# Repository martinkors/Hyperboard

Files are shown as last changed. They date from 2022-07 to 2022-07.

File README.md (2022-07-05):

# Hyperboard

A custom development board based on an STM32F479VIT6, used to test custom written drivers.

This board is only a prototype, there are many things that could be improved. It is not advised to follow the design of this board, but instead only use it as a very simplified reference board.

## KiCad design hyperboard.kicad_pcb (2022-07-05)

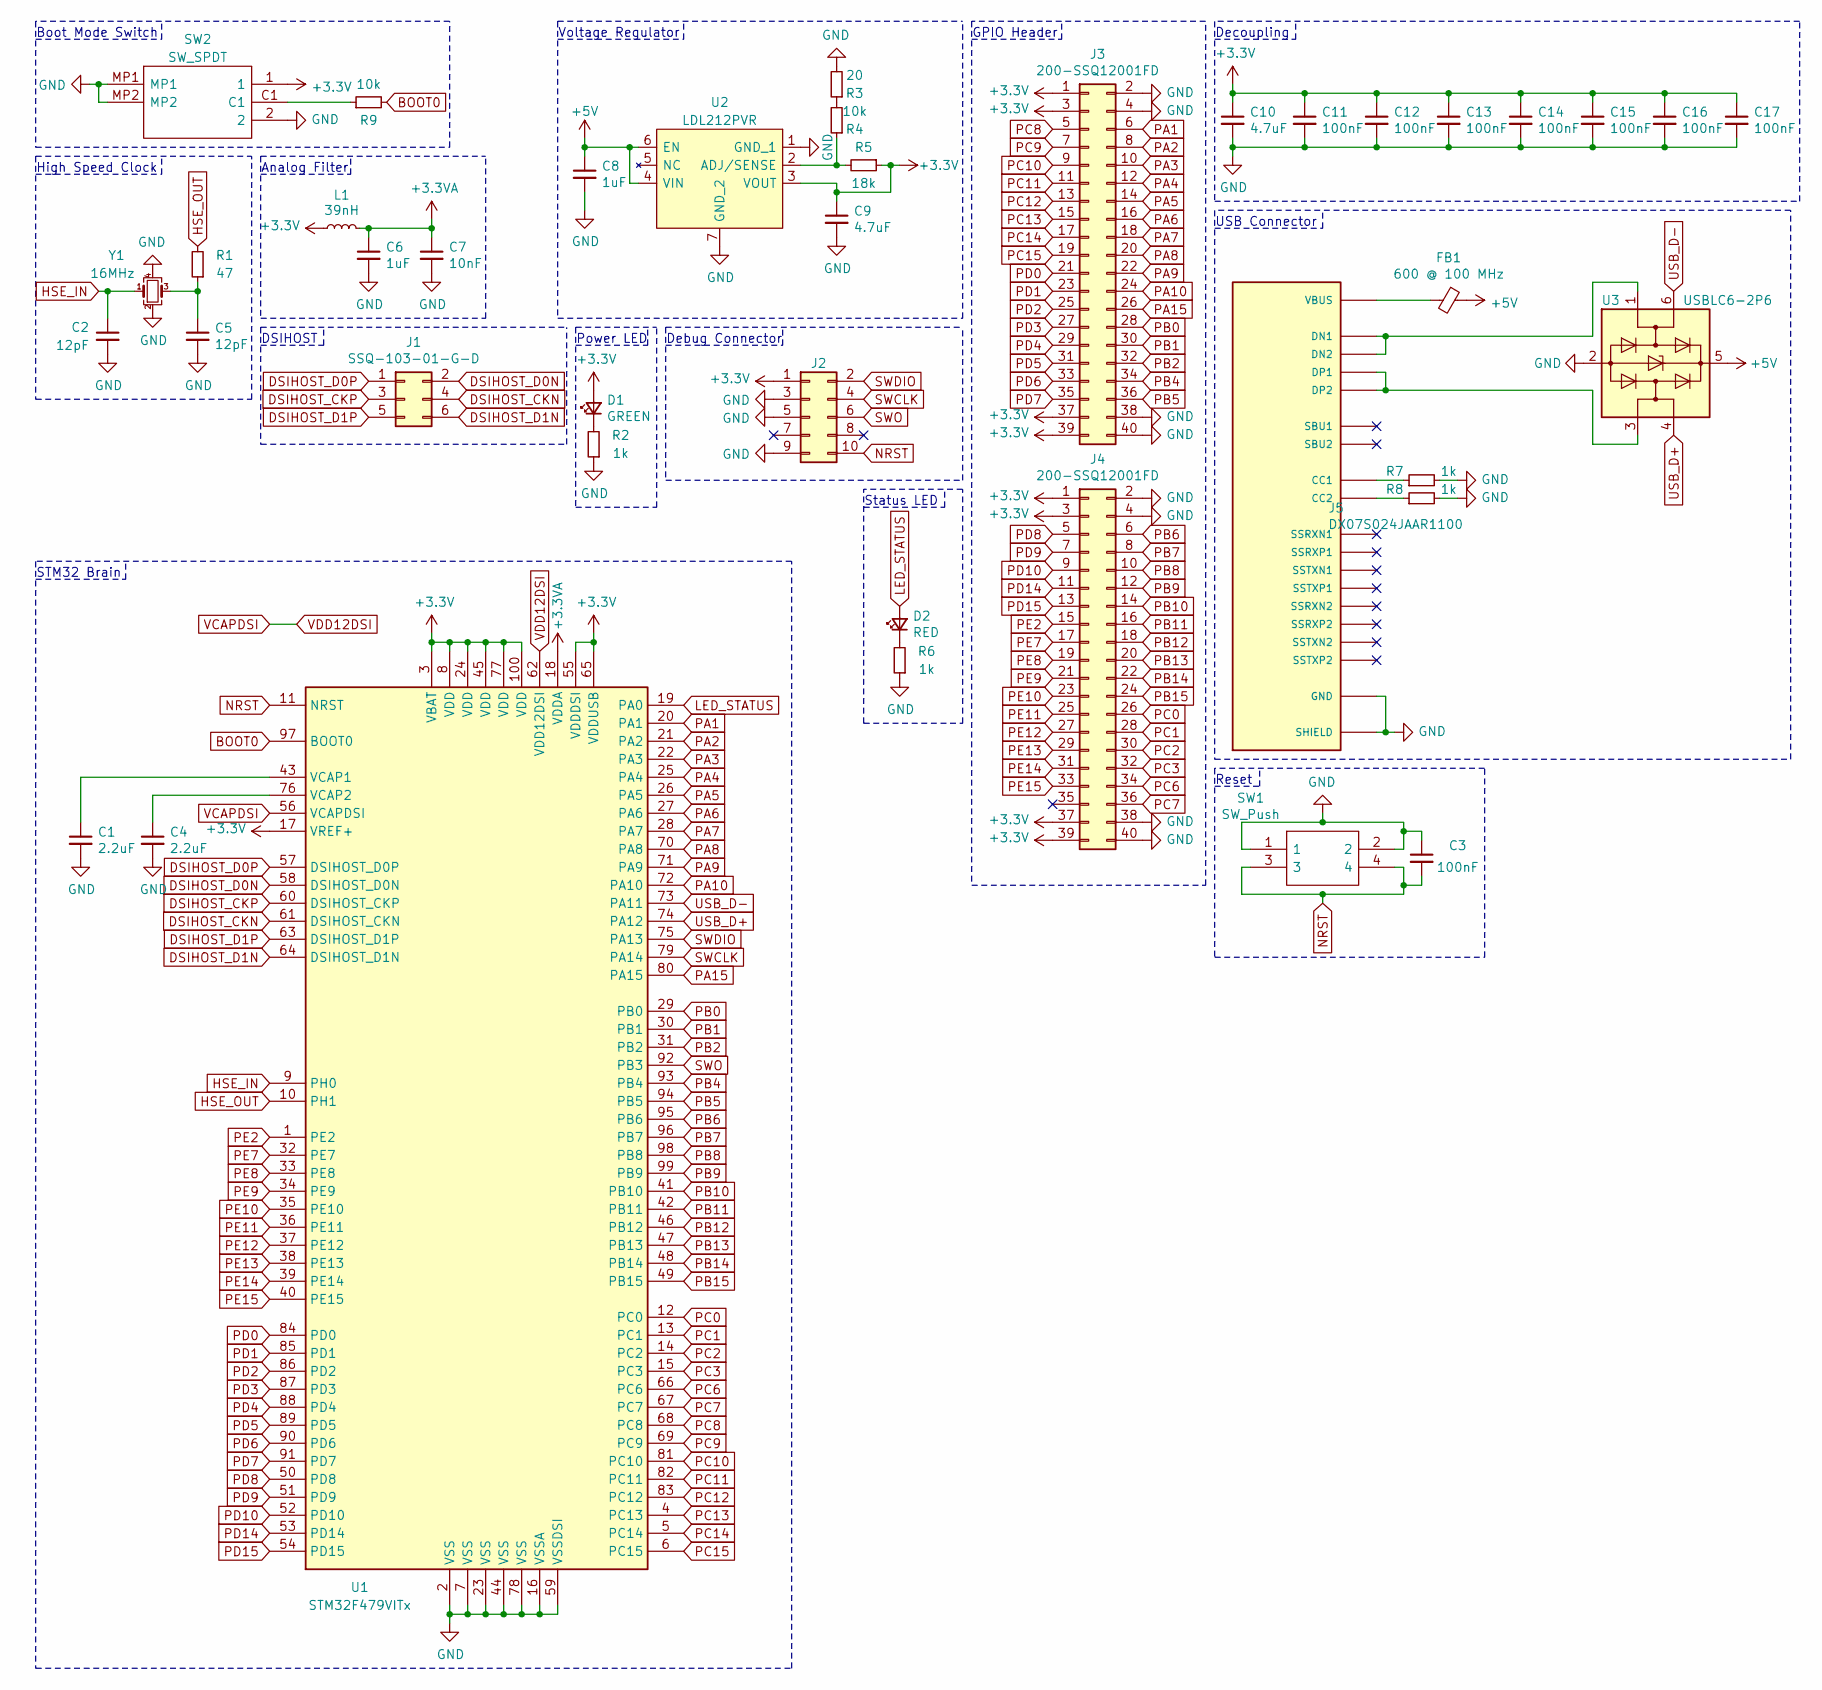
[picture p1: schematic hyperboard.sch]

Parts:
C1, C4: 2.2uF; C_0603_1608Metric; Mouser Part Number 187-CL10A225KA8NNNC; LCSC Part # C23630
C2, C5: 12pF; C_0603_1608Metric; Mouser Part Number 187-CL10C120JB81PNC; LCSC Part # C38523
C3, C11, C12, C13, C14, C15, C16, C17: 100nF; C_0402_1005Metric; Mouser Part Number 187-CL05B104KQ5NNNC; LCSC Part # C1525
C6: 1uF; C_0402_1005Metric; Mouser Part Number 187-CL05A105KQ5NNNC; LCSC Part # C52923
C7: 10nF; C_0402_1005Metric; Mouser Part Number 187-CL05B103JO5NNNC; LCSC Part # C15195
C8: 1uF; C_0402_1005Metric; Mouser Part Number 187-CL05A105KQ5NNNC; LCSC Part # C1525
C9: 4.7uF; C_0603_1608Metric; Mouser Part Number 187-CL10A475KQ8NNNC; LCSC Part # C1525
C10: 4.7uF; C_0603_1608Metric; Mouser Part Number 187-CL10A475KQ8NNNC; LCSC Part # C19666
D1: GREEN; LED_0805_2012Metric; Mouser Part Number 710-150080VS75000; LCSC Part # C188728
D2: RED; LED_0805_2012Metric; Mouser Part Number 710-150080RS75000; LCSC Part # C729289
FB1: 600 @ 100 MHz; L_0805_2012Metric; Mouser Part Number 710-742792040; LCSC Part # C1017
J1: SSQ-103-01-G-D; PinSocket_2x03_P2.54mm_Vertical; Mouser Part Number 200-SSQ10301GD
J2: FTSH-105-01-L-DV-K-TR; FTSH10501LDVKTR; Mouser Part Number 200-FTSH10501LDVKTR
J3, J4: 200-SSQ12001FD; SSQ-120-XX-YYY-D; Mouser Part Number 200-SSQ12001FD
J5: DX07S024JAAR1100; PARTREV 1.03; Mouser Part Number 656-DX07S024JAAR1100
L1: 39nH; L_0402_1005Metric; Mouser Part Number 710-7447840139; LCSC Part # C26443
R1: 47; R_0603_1608Metric; Mouser Part Number 667-ERJ-UP3J470V; LCSC Part # C23182
R2, R6, R7, R8: 1k; R_0603_1608Metric; Mouser Part Number 667-ERJ-UP3F1001V; LCSC Part # C21190
R3: 20; R_0603_1608Metric; Mouser Part Number 667-ERJ-UP3F20R0V; LCSC Part # C21190
R4: 10k; R_0603_1608Metric; Mouser Part Number 667-ERJ-UP3F1002V; LCSC Part # C22967
R5: 18k; R_0603_1608Metric; Mouser Part Number 667-ERJ-UP3F1802V; LCSC Part # C25804
R9: 10k; R_0603_1608Metric; Mouser Part Number 667-ERJ-UP3F1002V; LCSC Part # C25804
SW1: SW_Push; SKQGAKE010; Mouser Part Number 688-SKQGAKE010
SW2: SW_SPDT; JSX08001SAQNL; Mouser Part Number 688-SSAJ120100; LCSC Part # C319019
U1: STM32F479VITx; LQFP-100_14x14mm_P0.5mm; Mouser Part Number 511-STM32F479VIT6
U2: LDL212PVR; DFN-6-1EP_2x2mm_P0.65mm_EP1x1.6mm; Mouser Part Number 511-LDL212PVR; LCSC Part # C9056
U3: USBLC6-2P6; SOT-666; Mouser Part Number 511-USBLC6-2P6; LCSC Part # C7519
Y1: 16MHz; Crystal_SMD_3225-4Pin_3.2x2.5mm; Mouser Part Number 344-NX3225SA16MHZT1; LCSC Part # C13738

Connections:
+3.3VA: C6.1, C7.1, L1.2, U1.18 (VDDA)
+3V3: C9.1, C10.1, C11.1, C12.1, C13.1, C14.1, C15.1, C16.1, C17.1, D1.2 (A), J2.1, J3.1, J3.3, J3.37, J3.39, J4.1, J4.3, J4.37, J4.39, L1.1, R5.1, SW2.1, U1.3 (VBAT), U1.8 (VDD), U1.17 (VREF+), U1.24 (VDD), U1.45 (VDD), U1.55 (VDDDSI), U1.65 (VDDUSB), U1.77 (VDD), U1.100 (VDD), U2.3 (VOUT)
+5V: C8.1, FB1.1, U2.4 (VIN), U2.6 (EN), U3.5 (VBUS)
BOOT0: R9.2, U1.97 (BOOT0)
DSIHOST_CKN: J1.4, U1.61 (DSIHOST_CKN)
DSIHOST_CKP: J1.3, U1.60 (DSIHOST_CKP)
DSIHOST_D0N: J1.2, U1.58 (DSIHOST_D0N)
DSIHOST_D0P: J1.1, U1.57 (DSIHOST_D0P)
DSIHOST_D1N: J1.6, U1.64 (DSIHOST_D1N)
DSIHOST_D1P: J1.5, U1.63 (DSIHOST_D1P)
GND: C1.2, C2.2, C3.1, C4.2, C5.2, C6.2, C7.2, C8.2, C9.2, C10.2, C11.2, C12.2, C13.2, C14.2, C15.2, C16.2, C17.2, J2.3, J2.5, J2.9, J3.2, J3.4, J3.38, J3.40, J4.2, J4.4, J4.38, J4.40, J5.1 (SHIELD), J5.2 (SHIELD), J5.3 (SHIELD), J5.4 (SHIELD), J5.A1 (GND), J5.A12 (GND), J5.B1 (GND), J5.B12 (GND), R2.1, R3.2, R6.1, R7.2, R8.2, SW1.1, SW1.2, SW2.2, SW2.MP1, SW2.MP2, U1.2 (VSS), U1.7 (VSS), U1.16 (VSSA), U1.23 (VSS), U1.44 (VSS), U1.59 (VSSDSI), U1.78 (VSS), U2.1 (GND_1), U2.7 (GND_2), U3.2 (GND), Y1.2, Y1.4
HSE_IN: C2.1, U1.9 (PH0), Y1.1
HSE_OUT: R1.2, U1.10 (PH1)
LED_STATUS: D2.2 (A), U1.19 (PA0)
NRST: C3.2, J2.10, SW1.3, SW1.4, U1.11 (NRST)
unnamed: C1.1, U1.43 (VCAP1)
unnamed: C4.1, U1.76 (VCAP2)
unnamed: C5.1, R1.1, Y1.3
unnamed: D1.1 (K), R2.2
unnamed: D2.1 (K), R6.2
unnamed: FB1.2, J5.A4 (VBUS), J5.A9 (VBUS), J5.B4 (VBUS), J5.B9 (VBUS)
unnamed: J5.A5 (CC1), R7.1
unnamed: J5.A6 (DP1), J5.B6 (DP2), U3.3 (I/O2)
unnamed: J5.A7 (DN1), J5.B7 (DN2), U3.1 (I/O1)
unnamed: J5.B5 (CC2), R8.1
unnamed: R3.1, R4.2
unnamed: R4.1, R5.2, U2.2 (ADJ/SENSE)
unnamed: R9.1, SW2.C1
PA1: J3.6, U1.20 (PA1)
PA2: J3.8, U1.21 (PA2)
PA3: J3.10, U1.22 (PA3)
PA4: J3.12, U1.25 (PA4)
PA5: J3.14, U1.26 (PA5)
PA6: J3.16, U1.27 (PA6)
PA7: J3.18, U1.28 (PA7)
PA8: J3.20, U1.70 (PA8)
PA9: J3.22, U1.71 (PA9)
PA10: J3.24, U1.72 (PA10)
PA15: J3.26, U1.80 (PA15)
PB0: J3.28, U1.29 (PB0)
PB1: J3.30, U1.30 (PB1)
PB2: J3.32, U1.31 (PB2)
PB4: J3.34, U1.93 (PB4)
PB5: J3.36, U1.94 (PB5)
PB6: J4.6, U1.95 (PB6)
PB7: J4.8, U1.96 (PB7)
PB8: J4.10, U1.98 (PB8)
PB9: J4.12, U1.99 (PB9)
PB10: J4.14, U1.41 (PB10)
PB11: J4.16, U1.42 (PB11)
PB12: J4.18, U1.46 (PB12)
PB13: J4.20, U1.47 (PB13)
PB14: J4.22, U1.48 (PB14)
PB15: J4.24, U1.49 (PB15)
PC0: J4.26, U1.12 (PC0)
PC1: J4.28, U1.13 (PC1)
PC2: J4.30, U1.14 (PC2)
PC3: J4.32, U1.15 (PC3)
PC6: J4.34, U1.66 (PC6)
PC7: J4.36, U1.67 (PC7)
PC8: J3.5, U1.68 (PC8)
PC9: J3.7, U1.69 (PC9)
PC10: J3.9, U1.81 (PC10)
PC11: J3.11, U1.82 (PC11)
PC12: J3.13, U1.83 (PC12)
PC13: J3.15, U1.4 (PC13)
PC14: J3.17, U1.5 (PC14)
PC15: J3.19, U1.6 (PC15)
PD0: J3.21, U1.84 (PD0)
PD1: J3.23, U1.85 (PD1)
PD2: J3.25, U1.86 (PD2)
PD3: J3.27, U1.87 (PD3)
PD4: J3.29, U1.88 (PD4)
PD5: J3.31, U1.89 (PD5)
PD6: J3.33, U1.90 (PD6)
PD7: J3.35, U1.91 (PD7)
PD8: J4.5, U1.50 (PD8)
PD9: J4.7, U1.51 (PD9)
PD10: J4.9, U1.52 (PD10)
PD14: J4.11, U1.53 (PD14)
PD15: J4.13, U1.54 (PD15)
PE2: J4.15, U1.1 (PE2)
PE7: J4.17, U1.32 (PE7)
PE8: J4.19, U1.33 (PE8)
PE9: J4.21, U1.34 (PE9)
PE10: J4.23, U1.35 (PE10)
PE11: J4.25, U1.36 (PE11)
PE12: J4.27, U1.37 (PE12)
PE13: J4.29, U1.38 (PE13)
PE14: J4.31, U1.39 (PE14)
PE15: J4.33, U1.40 (PE15)
SWCLK: J2.4, U1.79 (PA14)
SWDIO: J2.2, U1.75 (PA13)
SWO: J2.6, U1.92 (PB3)
USB_D+: U1.74 (PA12), U3.4 (I/O2)
USB_D-: U1.73 (PA11), U3.6 (I/O1)
VCAPDSI: U1.56 (VCAPDSI), U1.62 (VDD12DSI)

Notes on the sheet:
USB Connector
Voltage Regulator
Analog Filter
High Speed Clock
Decoupling
Boot Mode Switch
STM32 Brain
GPIO Header
Power LED
DSIHOST
Debug Connector
Status LED
Reset

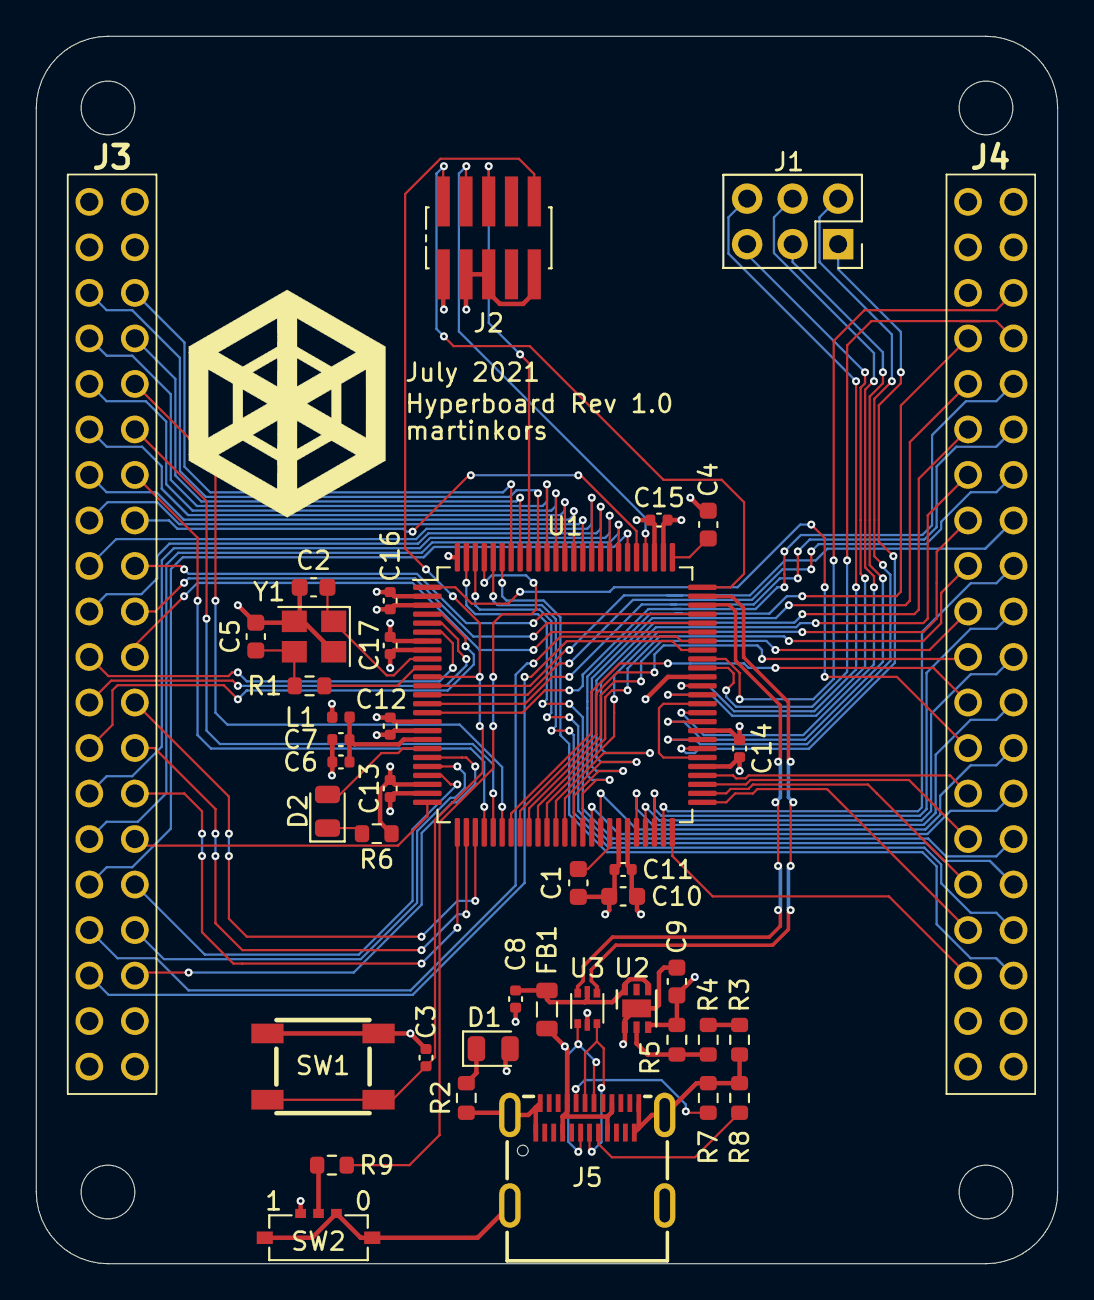
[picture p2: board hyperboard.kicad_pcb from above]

Board: 4 copper layers, 57.0 x 68.5 mm, 41 parts (0 on the bottom side), 97 nets.
